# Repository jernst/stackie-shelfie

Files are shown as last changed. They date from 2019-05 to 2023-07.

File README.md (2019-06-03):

Stackie-Shelfie: a stackable, 3D-printable shelf system
=======================================================

The problem
-----------

Too many little things that should be organized better.

I wanted some kind of pluggable system with lots of different types of
parts that all somehow can be plugged into each other, and that also can
be taken apart again.

It should be sturdier than Lego.

Oh, and I own a 3D printer.

The solution
------------

Here's an example:

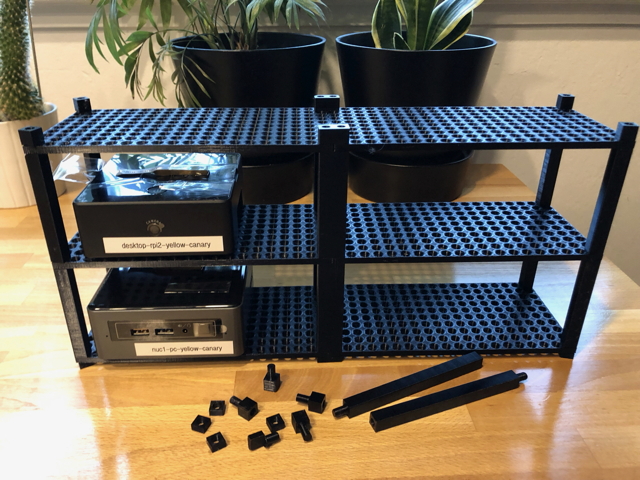
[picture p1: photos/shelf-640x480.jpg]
Shelf and parts


The principles
--------------

Everything is metric, with the basic unit being a cube that's 10mm wide.
Everything is a multiple of that basic unit, except that shelves are half
that to save on material.

The basic connector is a cylinder that slides through and into other parts.
On my printer, the defaults work so that the parts don't fall apart, even
without glue, but can be pulled apart again.

The connector is tapered on one end, so it isn't too hard to insert.

And on the other, it is rounded. This smooth rounding takes a lot of
computation time when computing the design, but it makes it far less
likely that parts break. At least that's my intent and experience so far.

The parts are defined using library modules that are simply parameterized
for the size of the part we want.

The parts so far
----------------

Note: it's really easy to create different dimensions for those parts:
just create your own OpenSCAD file and edit the parameters.

A 10 x 20 unit (e.g. 100mm x 200mm x 5mm) shelf.

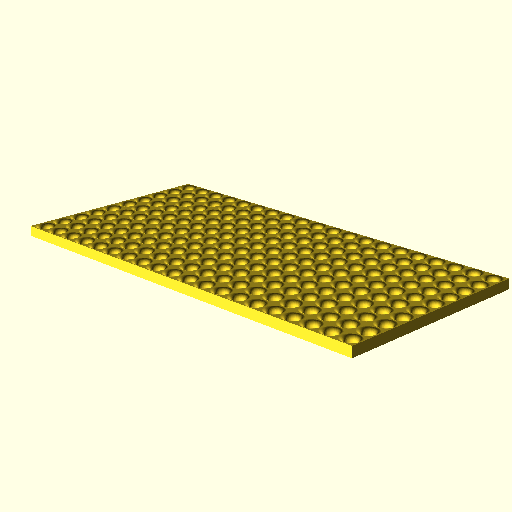
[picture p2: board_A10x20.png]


A one-unit peg, 8 units tall and whose connector is long enough to pass
through the board and into another part:

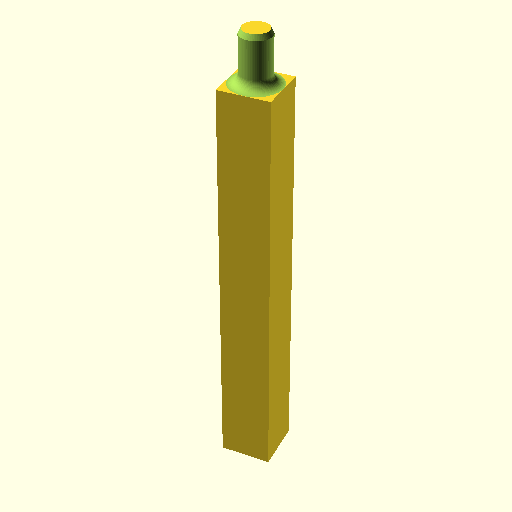
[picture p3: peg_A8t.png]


A similar peg, but only 1 unit tall:

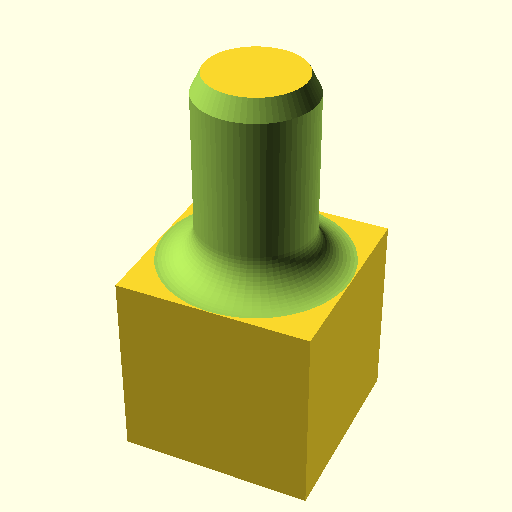
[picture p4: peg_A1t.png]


A similar peg, but 12 units tall:

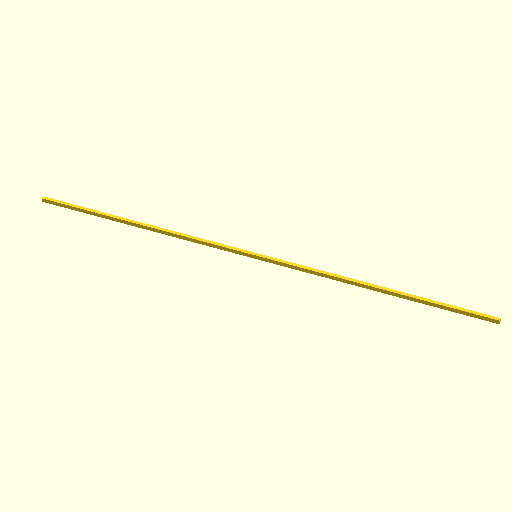
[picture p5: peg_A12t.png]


A double-wide peg, 8 units tall, that can serve double-duty to also
connect two adjecent boards. It's used in the photo above.

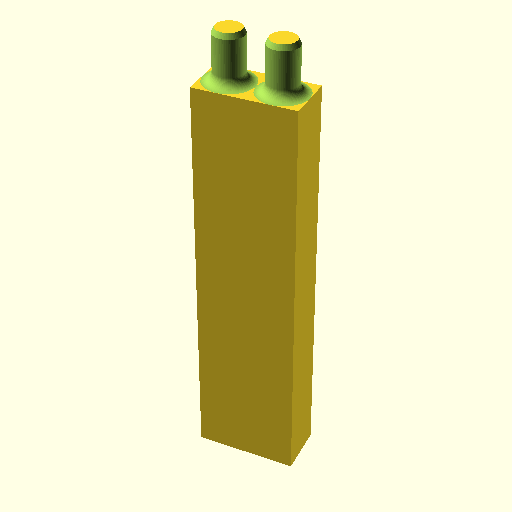
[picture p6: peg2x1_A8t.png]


Same, but only one unit tall:

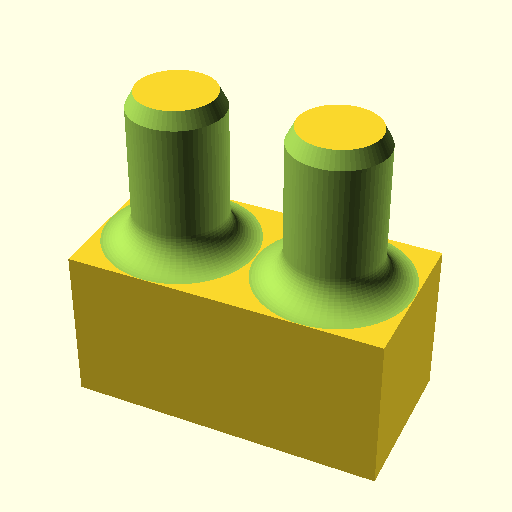
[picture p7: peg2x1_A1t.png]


A foot, for the bottom below the board:

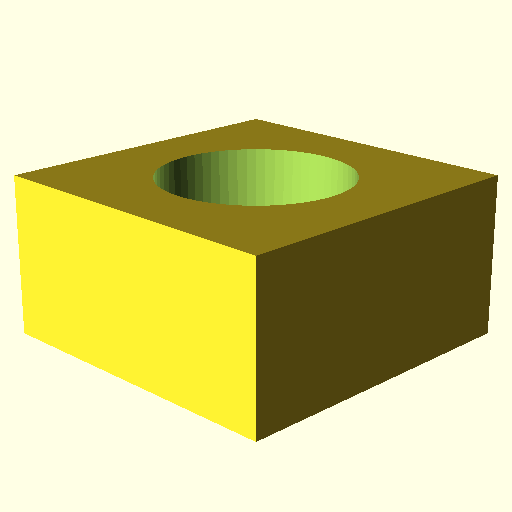
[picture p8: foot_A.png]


A double-foot that also plays double duty:

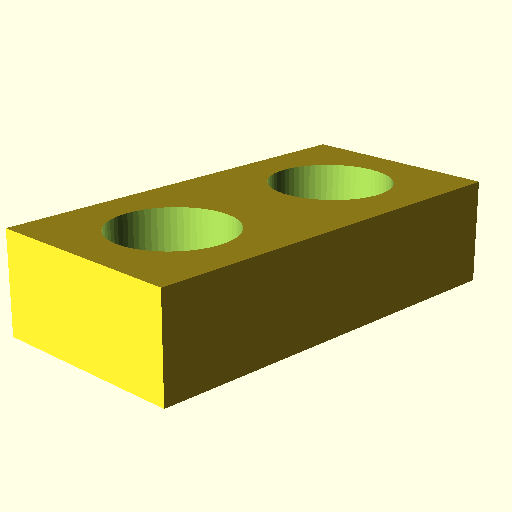
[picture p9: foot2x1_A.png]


A peg that can be used to keep things from moving around
on the shelf. It has a regular-size cylinder but is only half a unit
wide at the top.

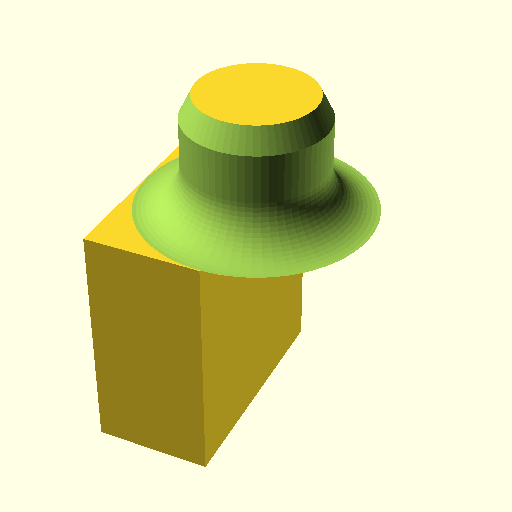
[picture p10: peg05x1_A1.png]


An X-shaped double-peg that acts as a strut (so the shelf does not
wobble) but is easily 3D-printable. You may want to print it with a
brim if needed.

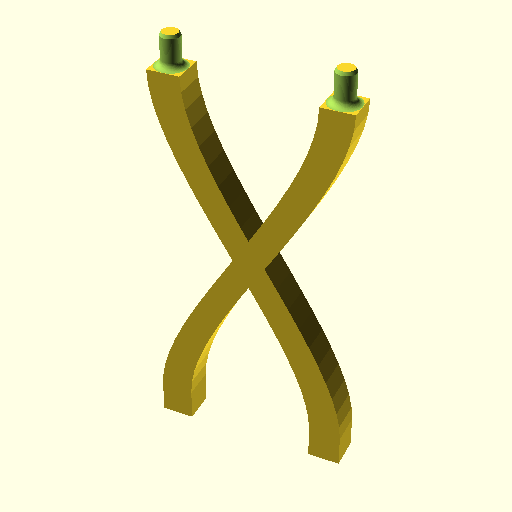
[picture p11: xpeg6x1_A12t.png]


How to use
----------

The models have been created in [OpenSCAD](http://www.openscad.org/), which
you need to have installed if you want to create modifications to these parts,
or new parts. If you use the parts as-is, you don't need it.

If you create a new part, say ``peg_A5t.scad``, you simply create that
file in the root directory, and run ``make`` at the command-line in that
directory. This should work out of the box on Linux (tested) and MacOS
(not tested, you may need developer tools installed) and, I'm sure, somehow
can be made to work on Windows.

The xpeg uses my Bezier-curve implementation contained in the
[JOSL](https://github.com/jernst/josl/) OpenSCAD library. Follow this
link to learn how to use the library.

The, you need to slice the STL files for your printer. How to best do that
depends on your 3D printer. I'm using a Prusa i3 and have been slicing them
in the [Prusa edition of Slic3r](https://www.prusa3d.com/prusaslicer/) with
defaults for PLA, using the 0.15mm "Optimal" settings. Except for the
half-peg, where I generated supports.

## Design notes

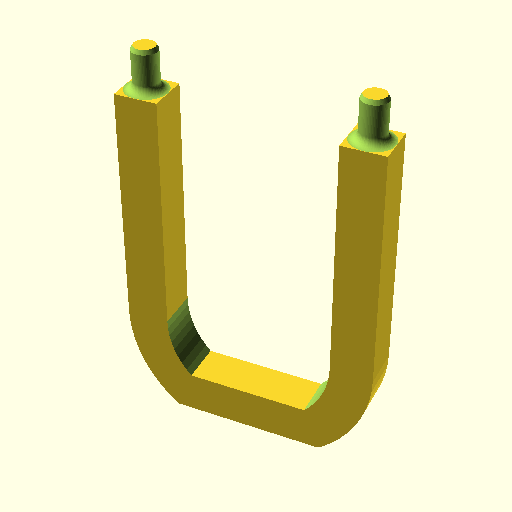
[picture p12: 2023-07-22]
arch6x1_A8t.png

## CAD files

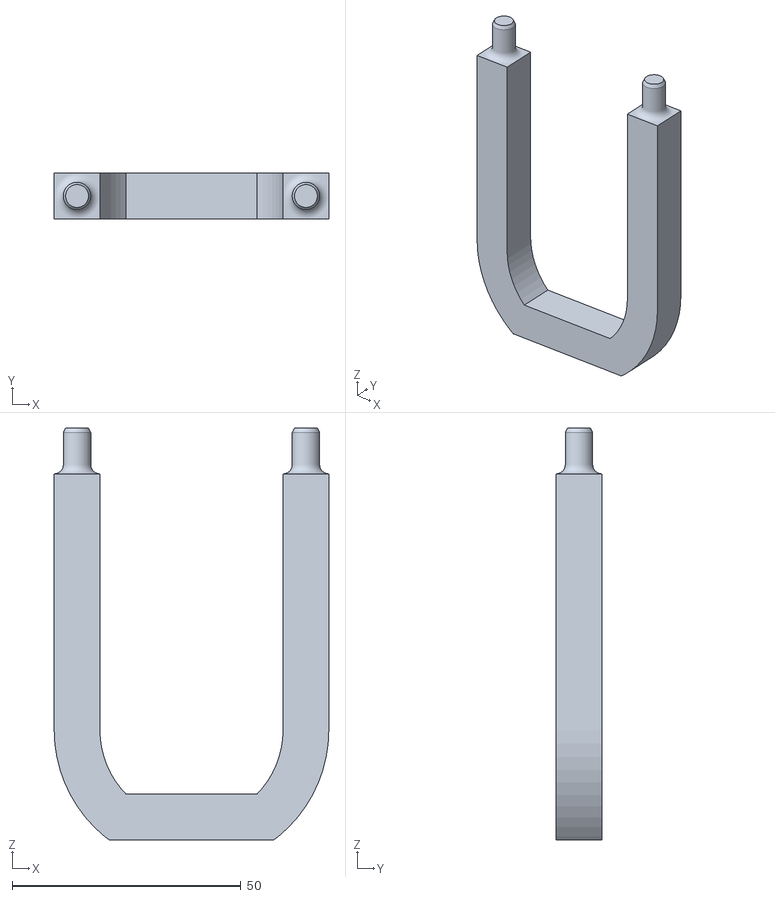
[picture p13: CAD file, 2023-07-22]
arch6x1_A8t.stl
60.0 x 10.0 x 90.0

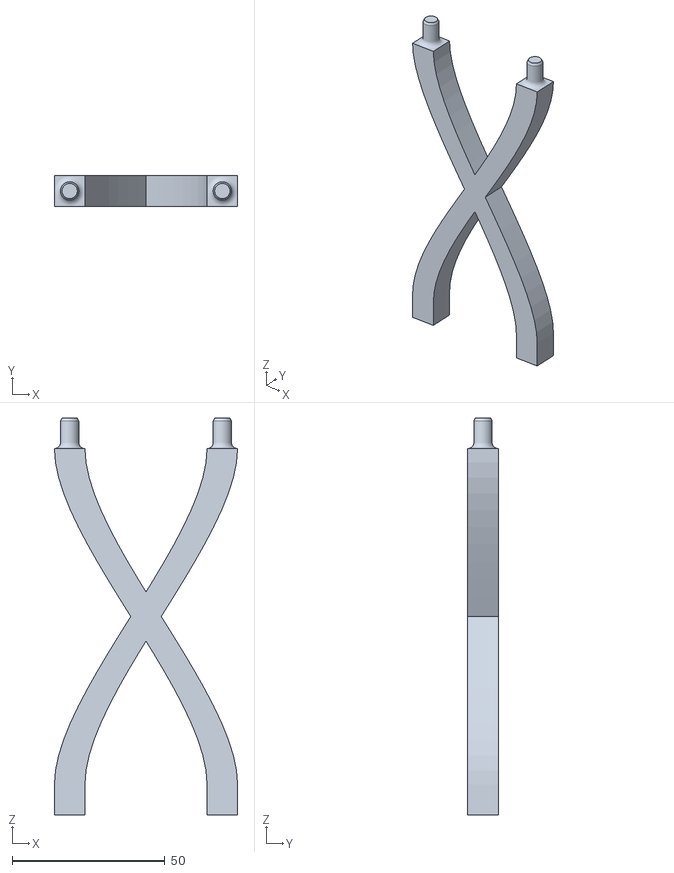
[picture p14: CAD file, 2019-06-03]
xpeg6x1_A12t.stl
60.0 x 10.0 x 130.0

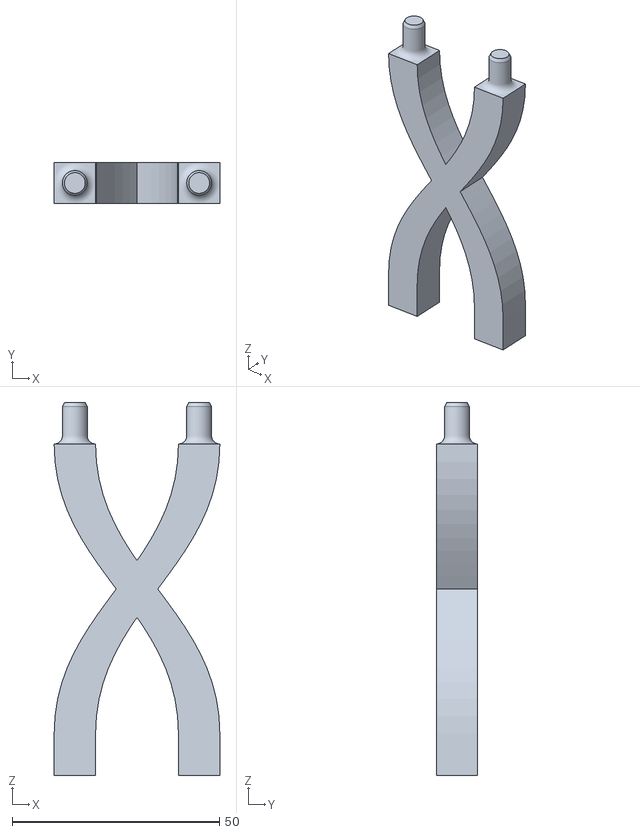
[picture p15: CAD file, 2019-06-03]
xpeg4x1_A8t.stl
40.0 x 10.0 x 90.0

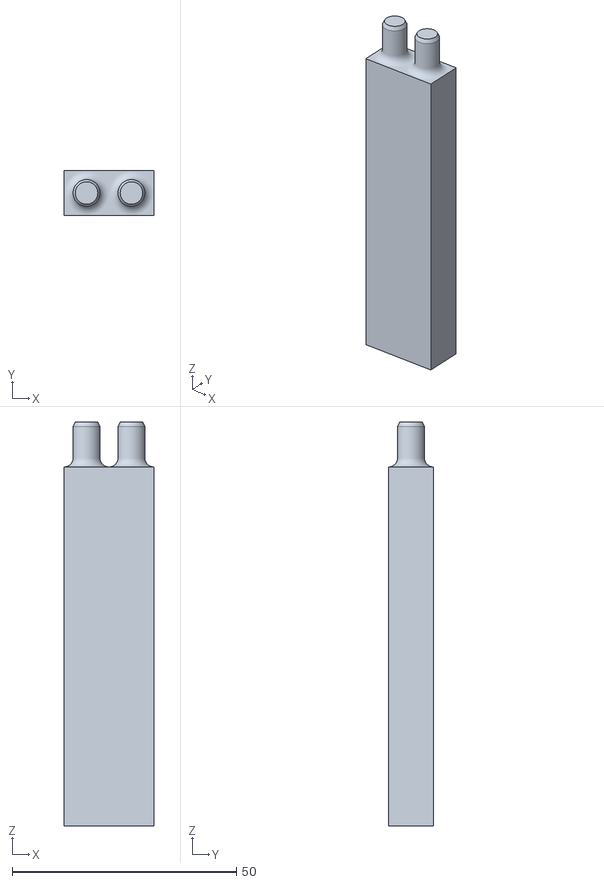
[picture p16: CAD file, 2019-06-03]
peg2x1_A8t.stl
20.0 x 10.0 x 90.0

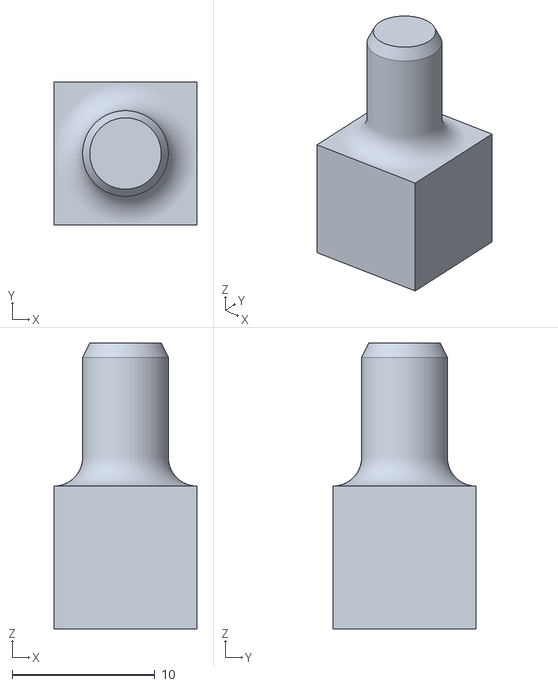
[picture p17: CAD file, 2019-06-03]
peg_A1t.stl
10.0 x 10.0 x 20.0

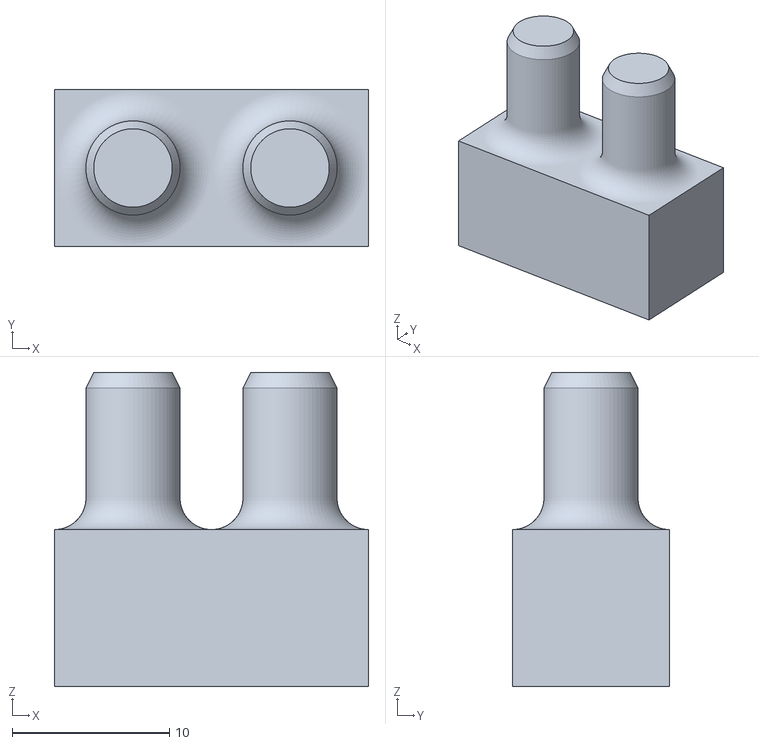
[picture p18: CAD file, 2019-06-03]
peg2x1_A1t.stl
20.0 x 10.0 x 20.0

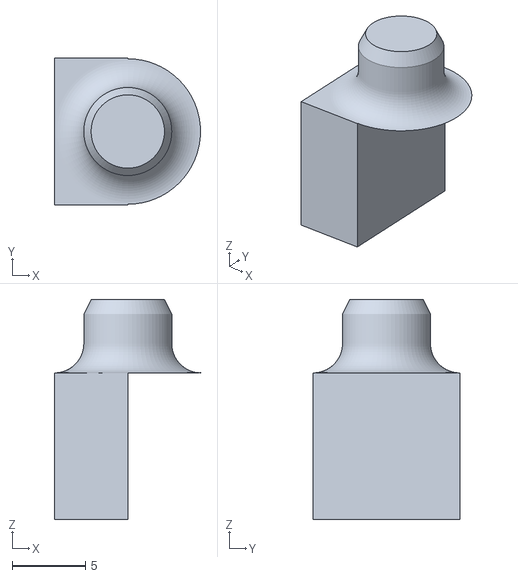
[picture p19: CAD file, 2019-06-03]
peg05x1_A1.stl
9.96 x 10.0 x 15.0

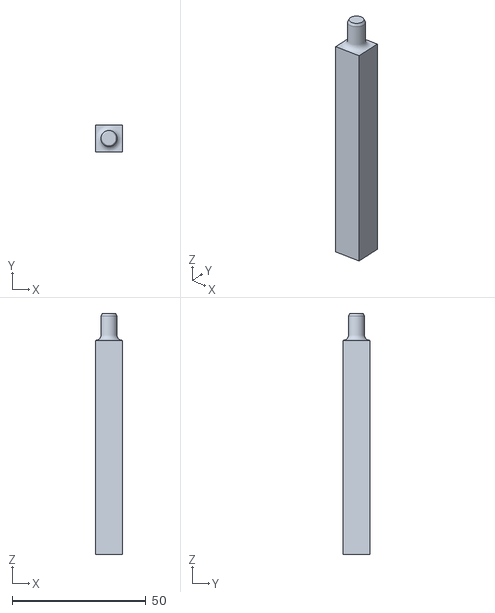
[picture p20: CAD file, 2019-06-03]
peg_A8t.stl
10.0 x 10.0 x 90.0

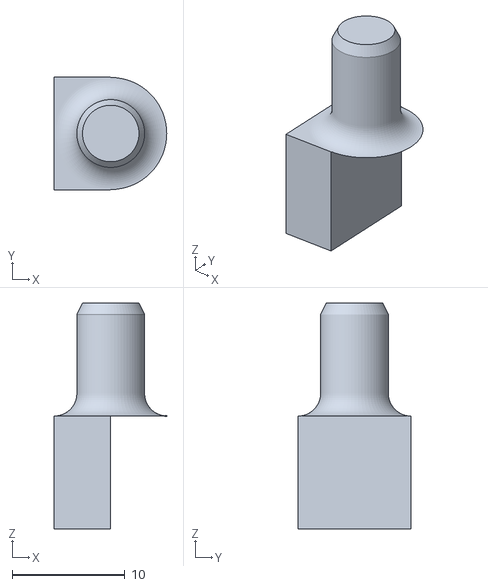
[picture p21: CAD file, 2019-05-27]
peg05x1_A1t.stl
9.96 x 10.0 x 20.0

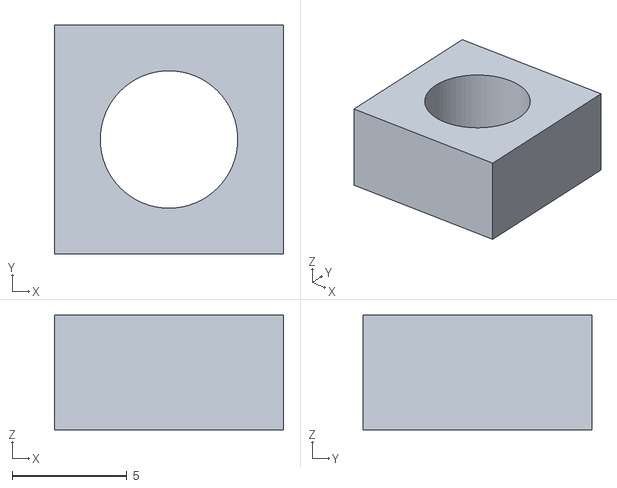
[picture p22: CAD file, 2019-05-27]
foot_A.stl
10.0 x 10.0 x 5.00

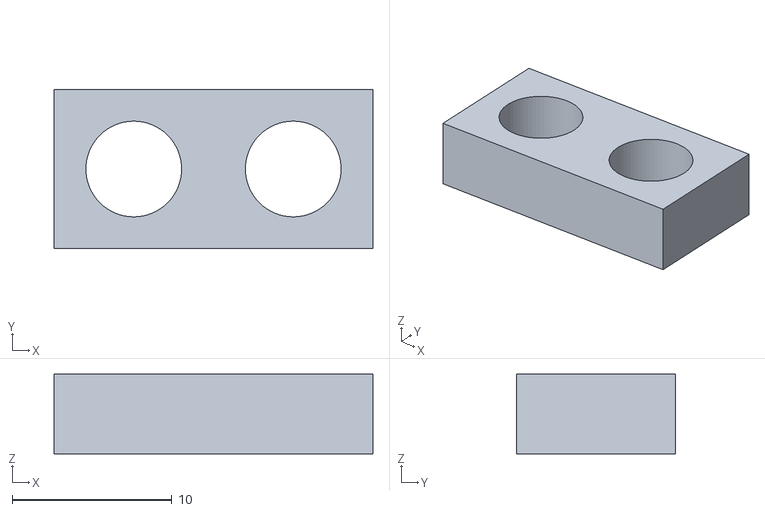
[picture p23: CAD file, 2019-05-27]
foot2x1_A.stl
20.0 x 10.0 x 5.00

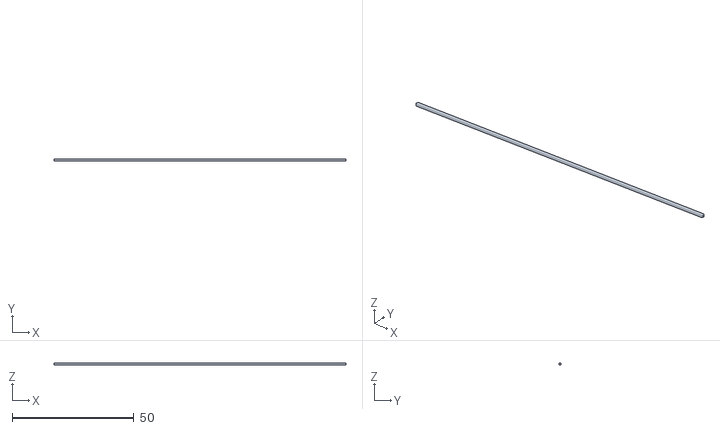
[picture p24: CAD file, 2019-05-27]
peg_A12t.stl
120.0 x 1.00 x 1.00

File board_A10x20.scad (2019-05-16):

//
// Stacky Board "A" 10x20 cm
//
// (C) 2019 Johannes Ernst.
// License: see package.
//

include <lib/board_A.scad>

board_A( 10, 20 );

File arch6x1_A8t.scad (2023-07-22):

//
// Stacky Arch "A" 6cm wide, 8cm tall
//
// (C) 2019 Johannes Ernst.
// License: see package.
//

include <lib/arch_A.scad>

arch_At( 6, 1, 8 );

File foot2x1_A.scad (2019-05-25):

//
// Stacky Double-Foot for Board "A" 0.5cm
//
// (C) 2019 Johannes Ernst.
// License: see package.
//

include <lib/foot_A.scad>

foot_A( 2, 1, 0.5 );

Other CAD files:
foot_A.scad
peg05x1_A1.scad
peg05x1_A1t.scad
peg2x1_A1t.scad
peg2x1_A8t.scad
peg_A12t.scad
peg_A1t.scad
peg_A8t.scad
xpeg4x1_A8t.scad
xpeg6x1_A12t.scad

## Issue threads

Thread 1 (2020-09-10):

How long does it take to render the board?

danielo515, 2020-09-10:
Hello,
Thanks for this awesome project, I love the idea.
I'm trying to render a smaller bersion of the board, like this `board_A( 10, 15 );`
but it has been rendering (I opened just that file on openscad) for more than an hour. How long is it expected torun?

danielo515, 2020-09-10:
Dam it! I can't believe it! I just finished at the exact moment I clicked the submit issue button, to the point that I thought "Uh, when did the submit button started to emit sounds" and it was openscad finishing the render!

Closed 2020-09-10.

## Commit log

2019-05-16 Refactorng stackyshelfie into stackie, and better modularization
    [board_A10x20.scad, peg_A8t.scad]
2019-05-19 Add peg taper Add a few more parts
    [foot_A.scad, peg_A1t.scad]
2019-05-19 Support pegs that take up more than one space on the grid
    [peg2x1_A8t.scad, peg_A12t.scad, peg_A8t.scad]
2019-05-25 Added double pegs and double foot
    [foot2x1_A.scad, peg2x1_A1t.scad]
2019-05-25 Attempting a half-peg
    [peg05x1_A1t.scad]
2019-05-27 Added generated files
    [foot2x1_A.stl, foot_A.stl, peg05x1_A1t.stl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]
2019-05-27 The half-wide peg should be flush, not go through, the board
    [peg05x1_A1.scad, peg05x1_A1.stl]
2019-06-03 Factor out cylinder for easier reuse
    [peg05x1_A1.stl, peg2x1_A1t.stl, peg2x1_A8t.stl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]
2019-06-03 Added xpeg
    [xpeg4x1_A8t.scad, xpeg4x1_A8t.stl, xpeg6x1_A12t.scad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]
2023-07-22 Files from long time ago, never checked in
    [arch6x1_A8t.scad, arch6x1_A8t.stl]
